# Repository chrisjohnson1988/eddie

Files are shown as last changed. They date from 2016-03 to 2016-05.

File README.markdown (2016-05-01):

# Eddie

This is Eddie. He is an arduino based soil, humidity and temperature sensor 
which transmits his readings to a raspberry pi node which relays the readings
to a [thingspeak channel](https://thingspeak.com/channels/92463).

Eddie is deployed in our greenhouse and powered by a 3.7v lithium ion battery
which is charged by a [cheap solar panel](http://www.amazon.co.uk/gp/product/B00EU6XZLQ)
using a [TP4056](http://www.amazon.co.uk/Cars-XCSOURCE%C2%AE-Lithium-Battery-Charging-TE106/dp/B00SR4FH4A).
Two DHT22 sensors are used, one for inside the greenhouse and one which is outside. The
project uses nRF24L01+ modules to transmit reading. Our setup uses the more powerful
nRF24L01+ with PA and LNA on the raspberry pi side to increase the transmission range.

There is also a [freeboard dashboard](http://freeboard.io/board/vIWE1d) of the readings.

## Building Eddie

The [arduino code](eddie/eddie.ino) makes use of some external libraries. These will 
need be installed in `~/sketchbook/libraries` before you can program the arduino
using the [Arduino IDE](https://www.arduino.cc/en/Main/Software).

The required libraries are:

- [DHT](https://github.com/markruys/arduino-DHT)
- [RF24](https://github.com/TMRh20/RF24.git)
- [RF24Network](https://github.com/TMRh20/RF24Network.git)

**The RF24Network needs to be customised to enable sleep mode. See `ENABLE_SLEEP_MODE` in `RF24Network_config.h`**

The wiring diagram below describes how the eddie side is wired up.

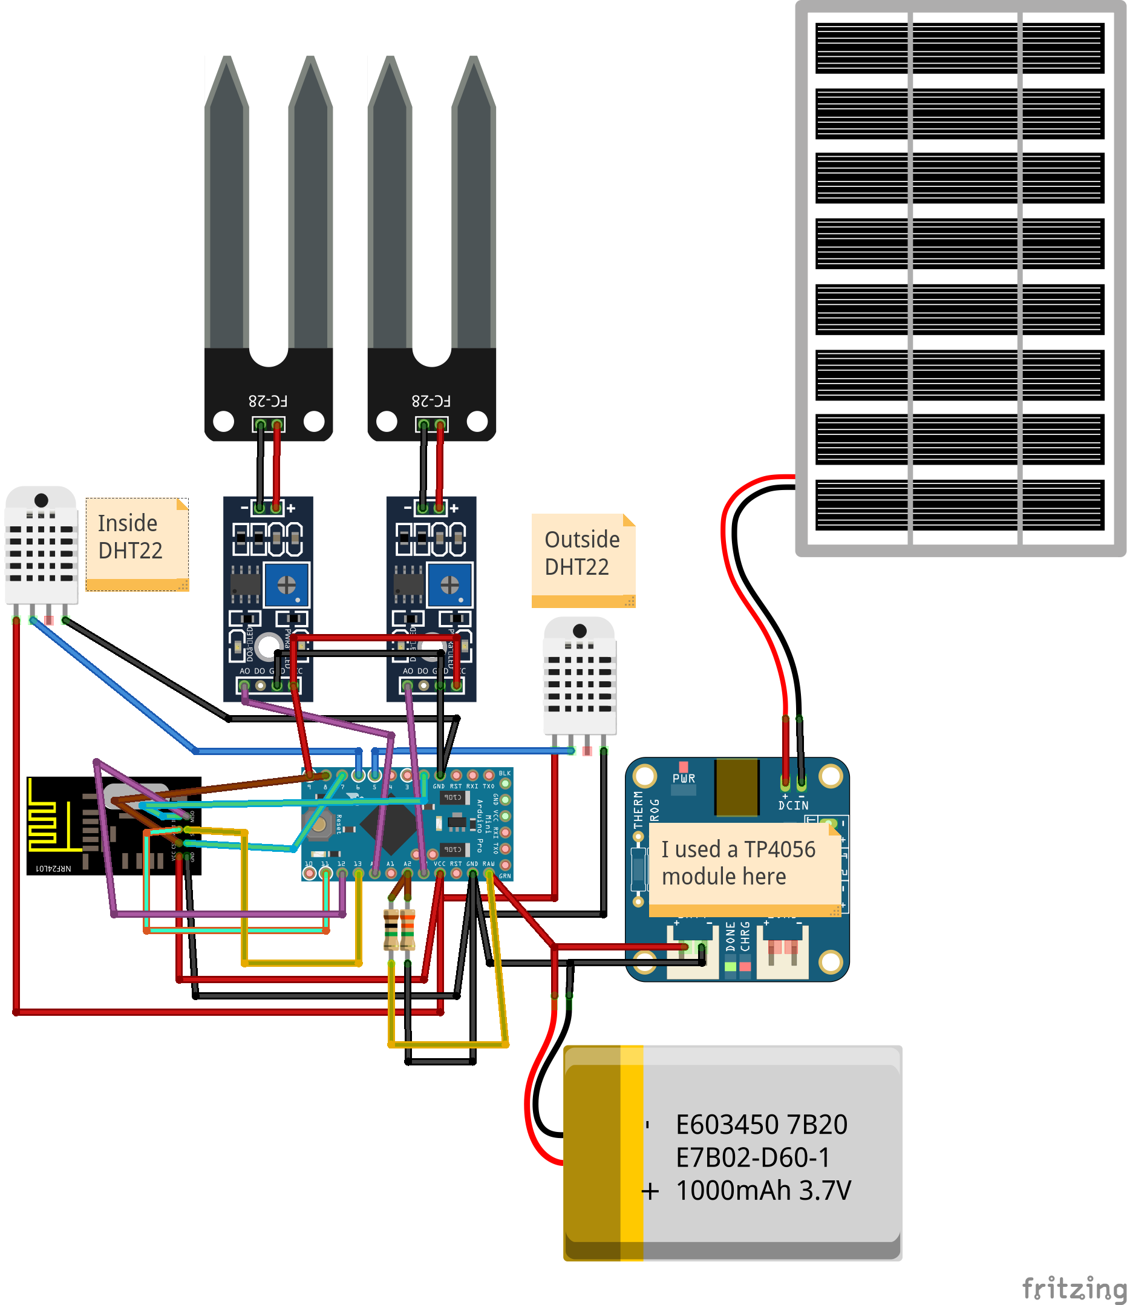
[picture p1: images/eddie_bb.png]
Eddie Wiring


### Mini Eddie

Eddie acts as a relay when he has enough charge. This allows mini eddie nodes to transmit
back to the raspberry pi via eddie. Mini Eddie nodes are much smaller and less power 
hungry than eddie. They only record soil moisture and fit snuggly in to the top of a
solar light sensor.

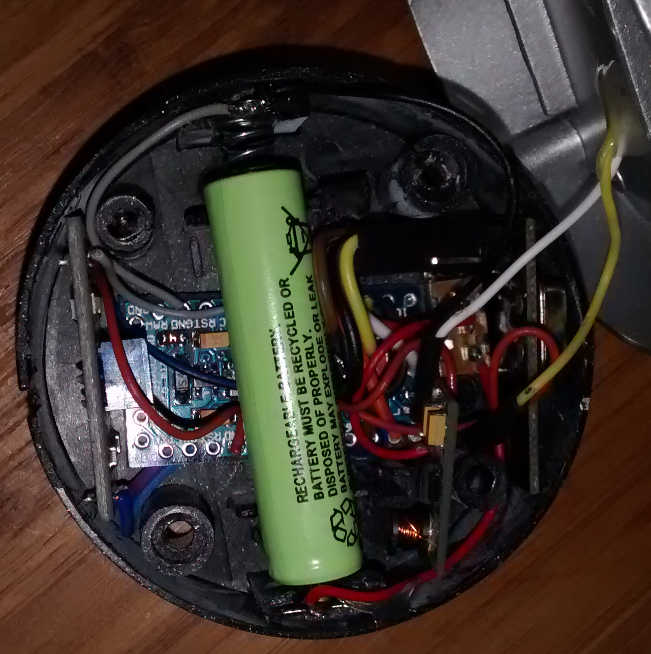
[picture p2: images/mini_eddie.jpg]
Mini Eddie


Below is the wiring for a mini eddie node. Powered by a single 1.2v solar recharged battery.

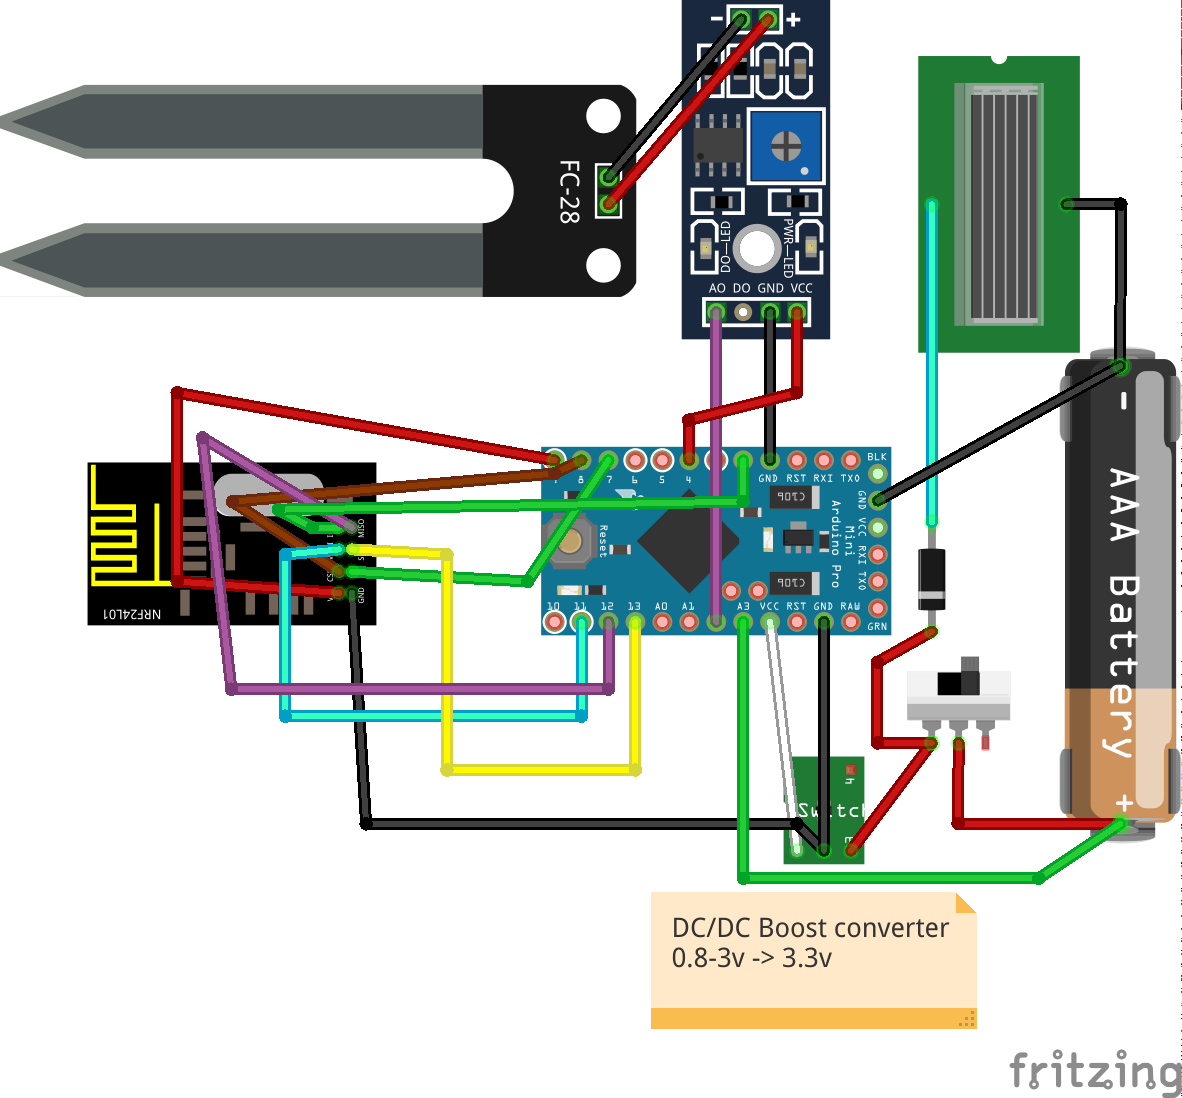
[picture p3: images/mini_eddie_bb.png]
Mini Eddie Wiring


## Building the Raspberry Pi Relay node

Wire up a nRF24L01+ module to the raspberry pi:

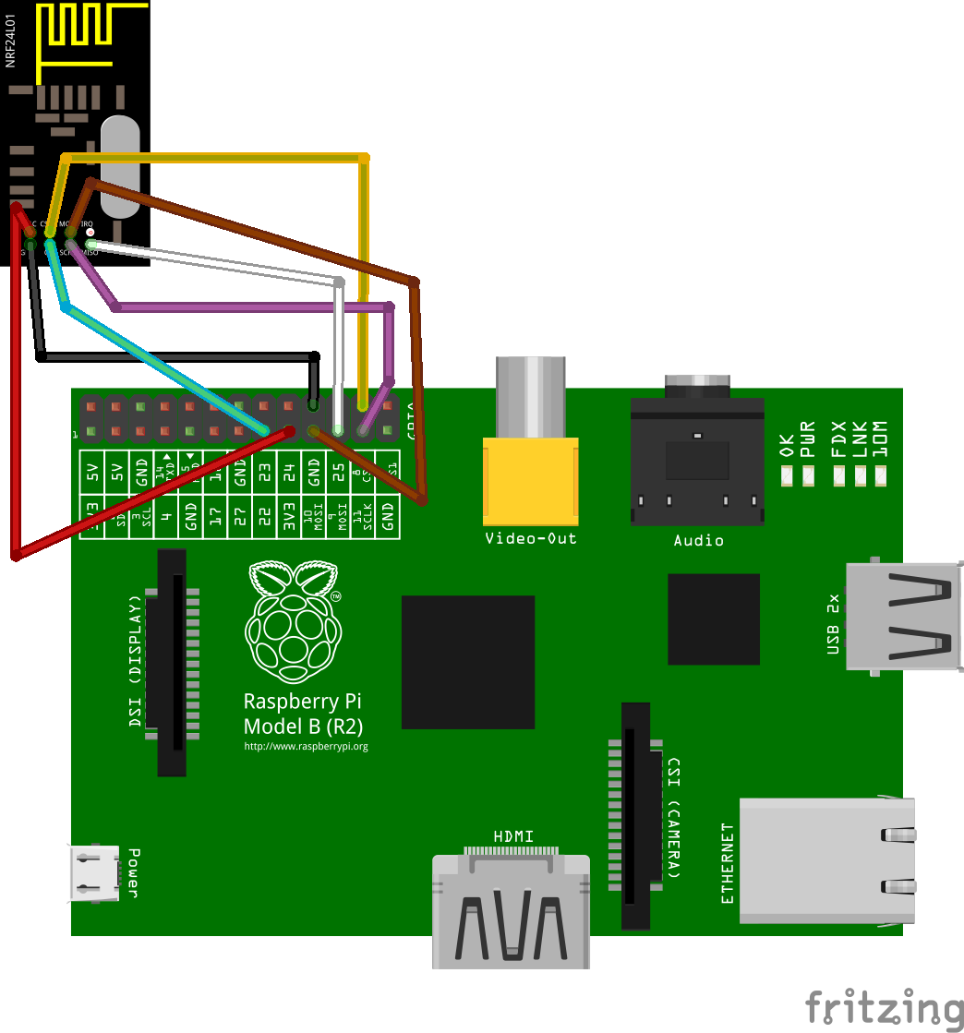
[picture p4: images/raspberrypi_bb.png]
Raspberry Pi Wiring


The `receiver` application makes use of some additional libraries. These will 
need to be installed on your raspberry pi before you can build the code.

The required libraries are:

- [RF24](https://github.com/TMRh20/RF24.git)
- [RF24Network](https://github.com/TMRh20/RF24Network.git)
- [libcurl](https://curl.haxx.se/libcurl/)

  This can be installed with apt:

        apt-get install libcurl4-gnutls-dev

Having installed the prerequisite libraries:

    make

You can now run the receiver application by

    EDDIE_API_KEY=Y0U4_AP1_K3Y MINI_EDDIE_API_KEY=An0THER_K3Y ./receiver

### Running on startup

You can get the application to run on boot of your raspberry pi by adding a line in `/etc/rc.local`.

Adjust the end of your `/etc/rc.local` to look like:

    EDDIE_API_KEY=Y0U4_AP1_K3Y MINI_EDDIE_API_KEY=An0THER_K3Y /opt/eddie/receiver &
    exit 0

# Acknowledgements

- [Solar Powered Mini-Weather Station](http://forum.mysensors.org/topic/841/solar-powered-mini-weather-station) - A very similar project
- [Home Automation for Geeks](http://homeautomationforgeeks.com/rf24software.shtml) - wiring setup
- [@wshelley](https://github.com/wshelley) - Thanks to Wayne for his help and ideas
- [@joncooper65](https://github.com/joncooper65) - Thanks to Jon for introducing me to ThingSpeak and the name Eco-Dome (which became eddie)

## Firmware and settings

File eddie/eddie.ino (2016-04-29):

#include <RF24Network.h>
#include <RF24.h>
#include <SPI.h>
#include <DHT.h>

DHT in_dht;
DHT ext_dht;
RF24 radio(7,8); 

RF24Network network(radio);

const uint16_t MY_ADDR = 01;
const uint16_t RASPBERRYPI_ADDR = 00;
const int SOIL_VCC = 9;
const int CYCLE = 16;
const int DHT_SLEEP = 6;

struct Payload {
  float in_temp;
  float in_hum;
  float ext_temp;
  float ext_hum;
  float voltage;
  unsigned int soil1;
  unsigned int soil2;
};

/**
 * Setup the radio, NRF24Network and the DHT22. We will broadcast sensor 
 * readings on frequency 108 (above Wifi routers)
 */
void setup(void) {
  SPI.begin();
  radio.begin();
  radio.enableDynamicPayloads();
  radio.setAutoAck(1);
  radio.setRetries(15,15);
  radio.setDataRate(RF24_250KBPS);
  radio.setPALevel(RF24_PA_MAX);
  radio.setCRCLength(RF24_CRC_8);
  network.begin(108, MY_ADDR);
  network.setup_watchdog(6); // 1 second cycle
  
  in_dht.setup(6);
  ext_dht.setup(5);
  pinMode(SOIL_VCC, OUTPUT);
}

/*
 * Read all the sensor values and store these in a payload struct.
 * The DHT22 sensors are contsantly powered, so the values can just be read.
 * However to extend the lifetime of the soil sensor, we will only power up to
 * take a reading.
 */
struct Payload read() {
  Payload data;
  data.in_temp  = in_dht.getTemperature();
  data.in_hum   = in_dht.getHumidity();
  data.ext_temp = ext_dht.getTemperature();
  data.ext_hum  = ext_dht.getHumidity();
  
  digitalWrite(SOIL_VCC, HIGH);
  delay(100); //Power up the soil sensor for 100 milliseconds before reading
  data.soil1 = analogRead(3);
  data.soil2 = analogRead(0);
  digitalWrite(SOIL_VCC, LOW);
  
  data.voltage = analogRead(2) * 4.3 / 1023;
  return data;
}

/**
 * Transmit a populated payload to the raspberry pi node.
 */
void send(Payload data) {
  network.update();
  RF24NetworkHeader header(RASPBERRYPI_ADDR);
  network.write(header,&data,sizeof(data));
}

/**
 * Reset the dht library timer. Since we are sleeping the arduino, millis() 
 * does not increase in real time.
 */
void reset() {  
  in_dht.resetTimer();
  ext_dht.resetTimer();
}

void loop() {
  Payload data = read();
  radio.powerUp();
  send(data);

  boolean slept = true;
  int on = max(min(data.voltage - 3.2, 1),0) * CYCLE;
  int off = CYCLE - on;
  if(on != 0) {
    slept = network.sleepNode(on, 0); // Sleep, wake on packet recieved
  }
  
  if(off != 0) {
    radio.powerDown();     
    network.sleepNode(off, 255); // Sleep with no chance of waking     
  }
  
  if(slept || off >= DHT_SLEEP) { 
    reset(); // Reset the dht sensors if slept longer than DHT_SLEEP
  }
}

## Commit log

2016-03-12 Init commit
    [arduino.fzz, raspberrypi.fzz]
2016-03-12 Reading only from arduino node
2016-03-19 Removing memory leak and cpu hog Adding additional soil sensor to rec
2016-03-19 Updating wiring diagram
    [arduino.fzz]
2016-04-25 Fixing odd behaviour where temperature and voltage readings are very variable.
    [eddie.ino]
2016-04-29 Turning the radio on and off based on voltage changing dht library
2016-04-29 Filtering out nan values
2016-05-01 Adding diagram for mini eddie
    [eddie.fzz, mini_eddie.fzz]
2016-05-01 Shrinking the mini eddie diagram
    [mini_eddie.fzz]
